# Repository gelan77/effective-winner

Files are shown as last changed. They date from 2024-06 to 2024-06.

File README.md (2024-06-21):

# Проект USB-VGA

Этот репозиторий содержит файлы для проекта USB-VGA, который демонстрирует возможности Raspberry Pi Pico в обработке USB, VGA и аудиовыходов. Ниже приведено краткое описание включенных файлов и их назначения.

## Файлы и директории

- **`CUI_SJ-3523-audio-jack.kicad_mod`**: Модуль KiCad для аудиоразъема.
- **`DSUB-15-L77HDE15SD1CH4F.kicad_mod`**: Модуль KiCad для разъема DSUB-15 VGA.
- **`Icon_`**: Файл иконки для проекта.
- **`MBR120_SOD-123.kicad_mod`**: Модуль KiCad для диода MBR120.
- **`USB-VGA.kicad_mod`**: Модуль KiCad для компонента USB-VGA.
- **`USB-VGA.kicad_pcb`**: Файл макета печатной платы KiCad.
- **`USB-VGA.kicad_prl`**: Файл проекта макета KiCad.
- **`USB-VGA.kicad_pro`**: Файл проекта KiCad.
- **`USB-VGA.kicad_sch`**: Файл схемы KiCad.
- **`USB-VGA.pdf`**: Версия схемы в формате PDF для удобного просмотра.
- **`VGA-USB.xlsx`**: Файл Excel с дополнительными данными о проекте или спецификацией материалов (BOM).
- **`fp-info-cache`**: Файл кеша информации о посадочных местах KiCad.
- **`fp-lib-table`**: Таблица библиотеки посадочных мест KiCad.
- **`sym-lib-table`**: Таблица библиотеки символов KiCad.

## Как использовать

1. **Схемы и макеты печатных плат**: Откройте файлы `.kicad_sch` и `.kicad_pcb` в KiCad для просмотра и редактирования схем и макетов печатных плат.
2. **Компоненты**: Файлы `.kicad_mod` содержат посадочные места для различных компонентов, используемых в проекте.
3. **Документация**: Обратитесь к `USB-VGA.pdf` для быстрого просмотра схемы.
4. **Спецификация материалов**: Файл `VGA-USB.xlsx` может содержать список компонентов и дополнительные детали проекта.

## Начало работы

Чтобы начать работу с этим проектом, клонируйте репозиторий и откройте файлы проекта в KiCad. Убедитесь, что у вас установлены все необходимые библиотеки и модули для беспроблемной работы.

```sh
git clone <repository-url>
```

## Лицензия

Этот проект лицензирован на условиях лицензии MIT. См. файл `LICENSE` для получения подробной информации.

---

Не стесняйтесь исследовать, модифицировать и вносить свой вклад в этот проект. Для любых вопросов или проблем, пожалуйста, откройте issue на странице репозитория.

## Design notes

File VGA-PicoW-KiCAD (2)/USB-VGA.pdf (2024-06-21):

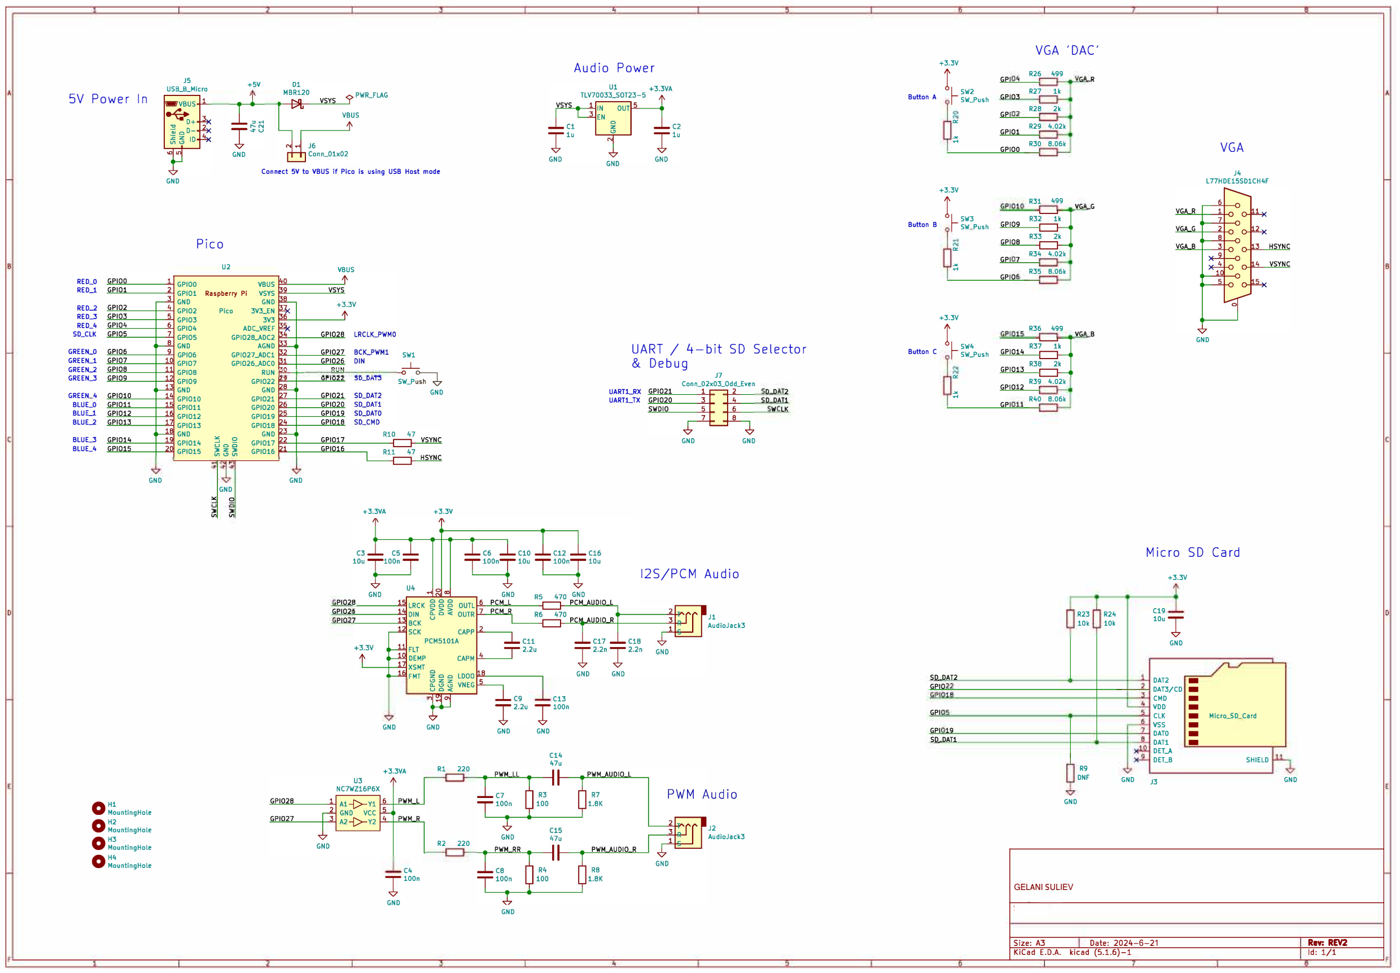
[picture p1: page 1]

5V Power In

RED_O
RED-1
RED-2
RED--3
RE0_4
SD_CLK
GREEN_O
GREEN-1
GREEN--2
GREEN_3
GREEN_4
BLUE_O
BLUU.
BLUE_2
BLUE----3
BLUE_4
GND

O!untingHole
ountingHole
ountingHole
ountingHole

J5
USBJLMicro

GND

Audio Power
+5V

Connect 5V to VBUS if Pico is using USB Host mode GND

Pico
U2
GPIOO VBUS
GPI01 Raspberry Pi VSYS
GND | GND
GPI02 Pico 3V3_EN
GPI03 | 3V3
GPI04 | ADCVREF
GPI05 | GPI028....ADC2
GND | AGND
GPI06 | GPI027_ADC1
GPl07 | GPl026....ADC0
GPIOB | RUN
GPI09 | GPI022
GND | GND
GPI010 | GPI021
GPl011 | GPI020
GPI012 | GPI019
GPI013 | GPI018
GND de | GND
GPI014 | GPI017
GPI015 GPI016
GND
| S'

VBUS

SW1 _l_
r""⁻⁻⁺⁻-~-----oSW_P

GND

PI028
GPI02
PIO 7

GND

+3.3VA +3.3V

GND

+3.3VA

DEMP
XSMT
FMT

C4
1100n
GND

GND

Ri 220

R2 220

GND

GND

C13
1100n
GND
C14
47,

UART/ 4-bit SD Selector
& Debug
UARTLRX
UARTLTX

J7
Conn_02x03_0dd_Even

GND GND

DD 2
SD DAT1

W LK

12S/PCM Audio
Ji
AudioJack3

J2
AudioJack3

+3.3Y
Button A

1
::Po,h

+3.3Y
Button B

1
::',,.,

+3.3Y
Button C

1
::Posh

SD DAT2
GPI0
GPI
GPI 19
SDDAT1

VGA 'DAC'
R26 499
GPI | G R
R27 1k
GPI03
R28 2k
GPI
R29 4.02k
GPI01
R30 8.06k
GPIO0

R31 499
| VG G

R34 4.02k
GPI 7
R35 B.06k
GPIO

R36 499
| VG B

R39 4.02k
GPIO 2
R40 8.06k
GPI

R23
1Dk

R9
DNF
GND

GELANI SULIEV
f
Sheet: /

R24
10k

Micro
+3.3Y
C19
1D,J
GND
DAT2
DAT3/CD
CMD
VDD
CLK

vss
DATO
DAT1
DET....A
DELB
GND J3

VGA
J4
L77HDE15SD1CH4F

GND

SD Card

- Micro_5D Card
SHIELD
GND
Size: A3 | Date: 2024-6-21 | Rev: REV2
KiCad E.D.A. kicad (5.1.6)-1 | Id: 1/1

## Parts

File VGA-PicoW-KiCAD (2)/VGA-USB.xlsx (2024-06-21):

VGA-USB
17/079/2020
Reference designators | Quantity | Manufacturer Part Number (MPN) | Manufacturer | Description | Value
C1, C2 | 2 | GCM188R71C105KA64J | Murata | CAP CER 1UF 16V X7R 0603 | 1u
C9, C11 | 2 | GRM188R71A225KE15D | Murata | CAP CER 2.2UF 10V X7R 0603 | 2.2u
C3, C10, C16, C19 | 4 | GRM188R61A106KE69J | Murata | CAP CER 10UF 10V X5R 0603 | 10u
C4, C5, C6, C7, C8, C12, C13 | 7 | GRM155R71E104KE14J | Murata | CAP CER 0.1UF 25V X7R 0402 | 100n
C14, C15, C21 | 3 | GRM219R60J476ME44D | Murata | CAP CER 47UF 6.3V X5R 0805 | 47u
C17, C18 | 2 | GRM155R71H222KA01D | Murata | CAP CER 2200PF 50V X7R 0402 | 2.2n
D1 | 1 | MBR120VLSFT1G | ON Semiconductor | DIODE SCHOTTKY 20V 1A SOD123FL | MBR120VLSFT1G
J1, J2 | 2 | SJ-3523-SMT-TR | CUI Devices | CONN JACK STEREO 3.5MM SMD R/A | SJ-3523-SMT
J3 | 1 | 104031-0811 | Molex | CONN MICRO SD CARD PUSH-PULL R/A | 104031-0811
J4 | 1 | L77HDE15SD1CH4F | Amphenol ICC (Commercial Products) | CONN DSUB HD RCPT 15POS R/A SLDR | L77HDE15SD1CH4F
J5 | 1 | 10103594-0001LF | Amphenol ICC (FCI) | CONN RCPT USB2.0 MICRO B SMD R/A | 10103594-0001LF
J6 | 1 | TSW-102-23-T-S | Samtec Inc. | CONN HEADER VERT 2POS 2.54MM | TSW-102-23-T-S
J7 | 1 | 67997-208HLF | Amphenol ICC (FCI) | CONN HEADER VERT 8POS 2.54MM | 67997-208HLF
R1, R2 | 2 | RC0402FR-07220RL | Yageo | RES SMD 220 OHM 1% 1/16W 0402 | 220
R3, R4 | 2 | RC0402FR-07100RL | Yageo | RES SMD 100 OHM 1% 1/16W 0402 | 100
R5, R6 | 2 | RC0402FR-07470RP | Yageo | RES SMD 470 OHM 1% 1/16W 0402 | 470
R7, R8 | 2 | RC0402FR-071K8L | Yageo | RES SMD 1.8K OHM 1% 1/16W 0402 | 1.8K
R10, R11 | 2 | RC0402FR-0747RL | Yageo | RES SMD 47 OHM 1% 1/16W 0402 | 47
R20, R21, R22, R27, R32, R37 | 6 | RC0402FR-071KP | Yageo | RES SMD 1K OHM 1% 1/16W 0402 | 1k
R23, R24 | 2 | RC0402FR-0710KP | Yageo | RES SMD 10K OHM 1% 1/16W 0402 | 10k
R26, R31, R36 | 3 | RC0402FR-07499RL | Yageo | RES SMD 499 OHM 1% 1/16W 0402 | 499
R28, R33, R38 | 3 | RC0402FR-072KL | Yageo | RES SMD 2K OHM 1% 1/16W 0402 | 2k
R29, R34, R39 | 3 | RC0402FR-074K02L | Yageo | RES SMD 4.02K OHM 1% 1/16W 0402 | 4.02k
R30, R35, R40 | 3 | RC0402FR-078K06L | Yageo | RES SMD 8.06K OHM 1% 1/16W 0402 | 8.06k
SW1, SW2, SW3, SW4 | 4 | 434133025816 | Würth Elektronik | TACT SWITCH 4.2X3.2MM VERTICAL T | 434133025816
U1 | 1 | TLV70033DDCR | Texas Instruments | IC REG LINEAR 3.3V 200MA SOT23-5 | TLV70033DDCR
U3 | 1 | NC7WZ16P6X | ON Semiconductor | IC BUF NON-INVERT 5.5V SC70-6 | NC7WZ16P6X
U4 | 1 | PCM5101APWR | Texas Instruments | IC DAC 16/24/32BIT 384K 20TSSOP | PCM5101APWR

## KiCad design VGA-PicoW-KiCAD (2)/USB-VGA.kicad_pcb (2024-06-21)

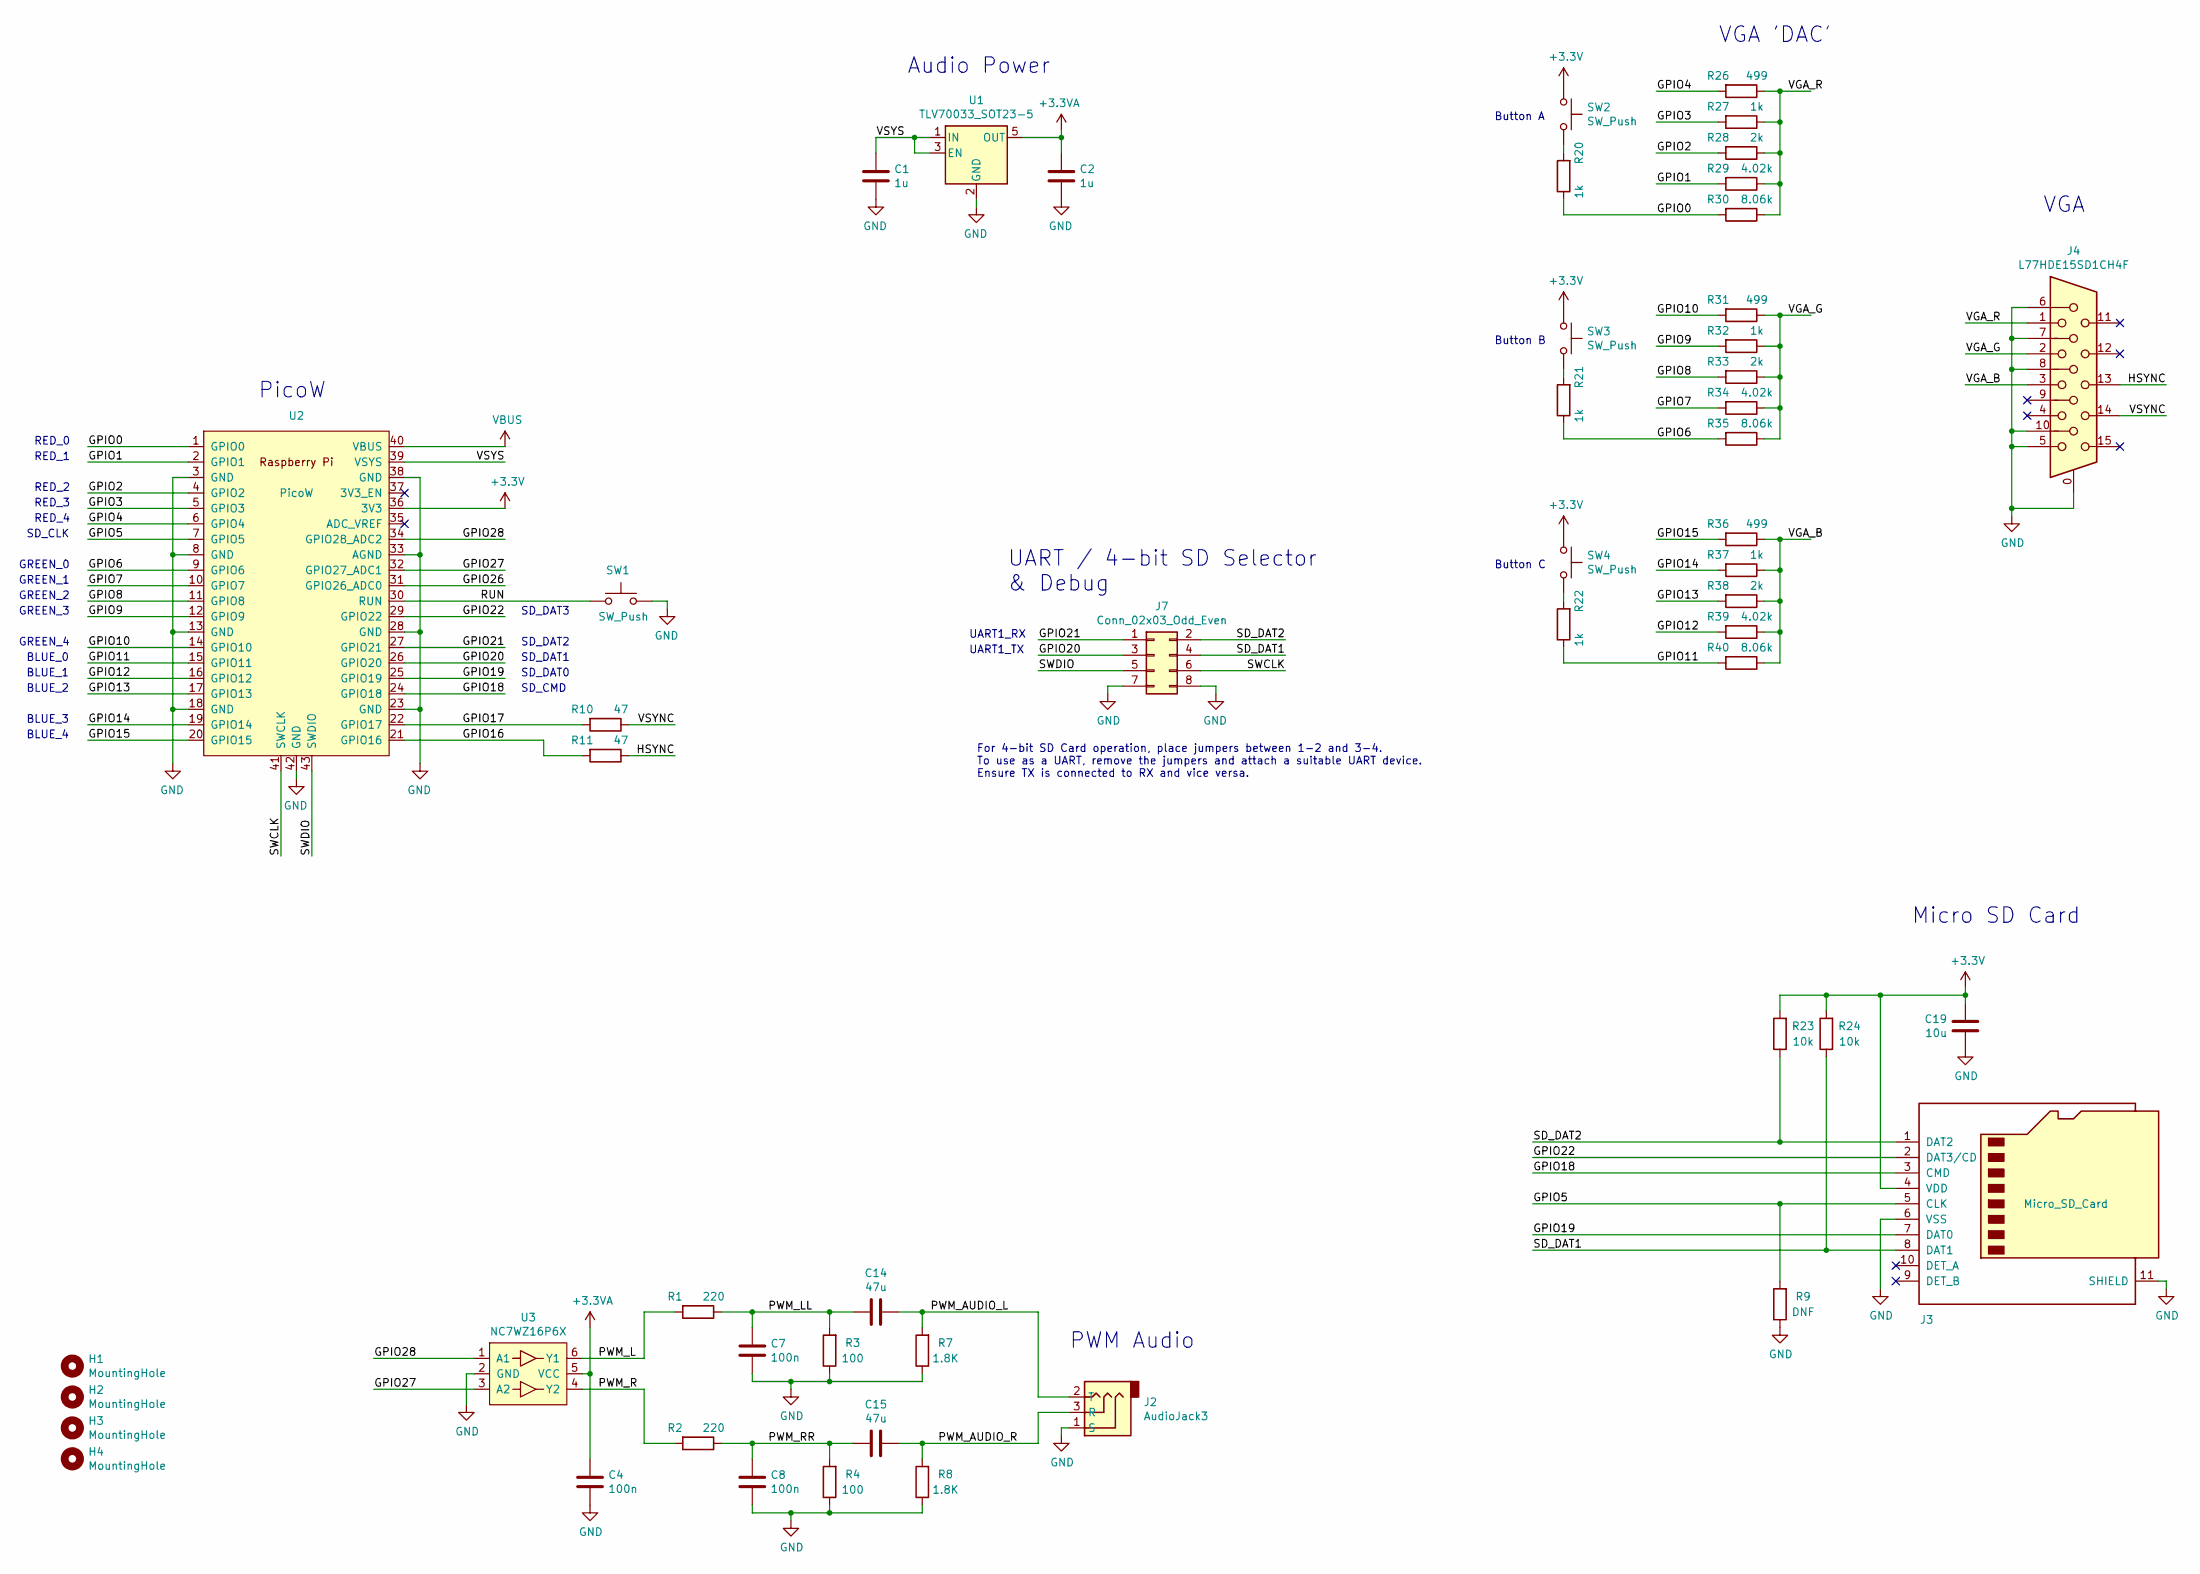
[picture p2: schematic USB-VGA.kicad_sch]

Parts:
C1, C2: 1u; C_0603_1608Metric
C4, C7, C8: 100n; C_0402_1005Metric
C14, C15: 47u; C_0805_2012Metric
C19: 10u; C_0603_1608Metric
H1, H2, H3, H4: MountingHole; MountingHole_2.7mm_M2.5
J2: AudioJack3; CUI_SJ-3523-audio-jack
J3: Micro_SD_Card; microSD_HC_Molex_104031-0811
J4: L77HDE15SD1CH4F; DSUB-15-L77HDE15SD1CH4F
J7: Conn_02x03_Odd_Even; PinHeader_2x04_P2.54mm_Vertical
R1, R2: 220; R_0402_1005Metric
R3, R4: 100; R_0402_1005Metric
R7, R8: 1.8K; R_0402_1005Metric
R9: DNF; R_0402_1005Metric
R10, R11: 47; R_0402_1005Metric
R20, R21, R22, R27, R32, R37: 1k; R_0402_1005Metric
R23, R24: 10k; R_0402_1005Metric
R26, R31, R36: 499; R_0402_1005Metric
R28, R33, R38: 2k; R_0402_1005Metric
R29, R34, R39: 4.02k; R_0402_1005Metric
R30, R35, R40: 8.06k; R_0402_1005Metric
SW1, SW2, SW3, SW4: SW_Push; SW_Push_1P1T_NO_Vertical_Wuerth_434133025816
U1: TLV70033_SOT23-5; SOT-23-5
U2: PicoW; RPi_PicoW_SMD_TH
U3: NC7WZ16P6X; SOT-363_SC-70-6

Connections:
+3.3VA: C2.1, C4.1, U1.5 (OUT), U3.5 (VCC)
+3V3: C19.1, J3.4 (VDD), R23.2, R24.2, SW2.1, SW3.1, SW4.1, U2.36 (3V3)
/GPIO0: R20.1, R30.2, U2.1 (GPIO0)
/GPIO1: R29.2, U2.2 (GPIO1)
/GPIO2: R28.2, U2.4 (GPIO2)
/GPIO3: R27.2, U2.5 (GPIO3)
/GPIO4: R26.2, U2.6 (GPIO4)
/GPIO5: J3.5 (CLK), R9.2, U2.7 (GPIO5)
/GPIO6: R21.1, R35.2, U2.9 (GPIO6)
/GPIO7: R34.2, U2.10 (GPIO7)
/GPIO8: R33.2, U2.11 (GPIO8)
/GPIO9: R32.2, U2.12 (GPIO9)
/GPIO10: R31.2, U2.14 (GPIO10)
/GPIO11: R22.1, R40.2, U2.15 (GPIO11)
/GPIO12: R39.2, U2.16 (GPIO12)
/GPIO13: R38.2, U2.17 (GPIO13)
/GPIO14: R37.2, U2.19 (GPIO14)
/GPIO15: R36.2, U2.20 (GPIO15)
/GPIO16: R11.2, U2.21 (GPIO16)
/GPIO17: R10.2, U2.22 (GPIO17)
/GPIO18: J3.3 (CMD), U2.24 (GPIO18)
/GPIO19: J3.7 (DAT0), U2.25 (GPIO19)
/GPIO20: J7.3, U2.26 (GPIO20)
/GPIO21: J7.1, U2.27 (GPIO21)
/GPIO22: J3.2 (DAT3/CD), U2.29 (GPIO22)
/GPIO26: U2.31 (GPIO26_ADC0)
/GPIO27: U2.32 (GPIO27_ADC1), U3.3 (A2)
/GPIO28: U2.34 (GPIO28_ADC2), U3.1 (A1)
/HSYNC: J4.13, R11.1
/PWM_AUDIO_L: C14.1, J2.2 (T), R7.2
/PWM_AUDIO_R: C15.1, J2.3 (R), R8.2
/PWM_L: R1.2, U3.6 (Y1)
/PWM_LL: C7.1, C14.2, R1.1, R3.2
/PWM_R: R2.2, U3.4 (Y2)
/PWM_RR: C8.1, C15.2, R2.1, R4.2
/RUN: SW1.1, U2.30 (RUN)
/SD_DAT1: J3.8 (DAT1), J7.4, R24.1
/SD_DAT2: J3.1 (DAT2), J7.2, R23.1
/SWCLK: J7.6, U2.41 (SWCLK)
/SWDIO: J7.5, U2.43 (SWDIO)
/VGA_B: J4.3, R36.1, R37.1, R38.1, R39.1, R40.1
/VGA_G: J4.2, R31.1, R32.1, R33.1, R34.1, R35.1
/VGA_R: J4.1, R26.1, R27.1, R28.1, R29.1, R30.1
/VSYNC: J4.14, R10.1
/VSYS: C1.1, U1.1 (IN), U1.3 (EN), U2.39 (VSYS)
GND: C1.2, C2.2, C4.2, C7.2, C8.2, C19.2, J2.1 (S), J3.6 (VSS), J3.11 (SHIELD), J4.0, J4.5, J4.6, J4.7, J4.8, J4.10, J7.7, J7.8, R3.1, R4.1, R7.1, R8.1, R9.1, SW1.2, U1.2 (GND), U2.3 (GND), U2.8 (GND), U2.13 (GND), U2.18 (GND), U2.23 (GND), U2.28 (GND), U2.33 (AGND), U2.38 (GND), U2.42 (GND), U3.2 (GND)
unnamed: R20.2, SW2.2
unnamed: R21.2, SW3.2
unnamed: R22.2, SW4.2
VBUS: U2.40 (VBUS)

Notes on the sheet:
GREEN_0
RED_3
RED_1
SD_DAT2
Button A
VGA
SD_CLK
BLUE_4
BLUE_0
UART1_TX
SD_DAT1
RED_4
PicoW
For 4-bit SD Card operation, place jumpers between 1-2 and 3-4. To use as a UART, remove the jumpers and attach a suitable UART device. Ensure TX is connected to RX and vice versa.
UART1_RX
VGA 'DAC'
Button B
Button C
GREEN_1
UART / 4-bit SD Selector & Debug
SD_DAT0
BLUE_3
SD_CMD
SD_DAT3
Micro SD Card
GREEN_4
RED_2
GREEN_2
Audio Power
PWM Audio
BLUE_1
GREEN_3
BLUE_2
RED_0

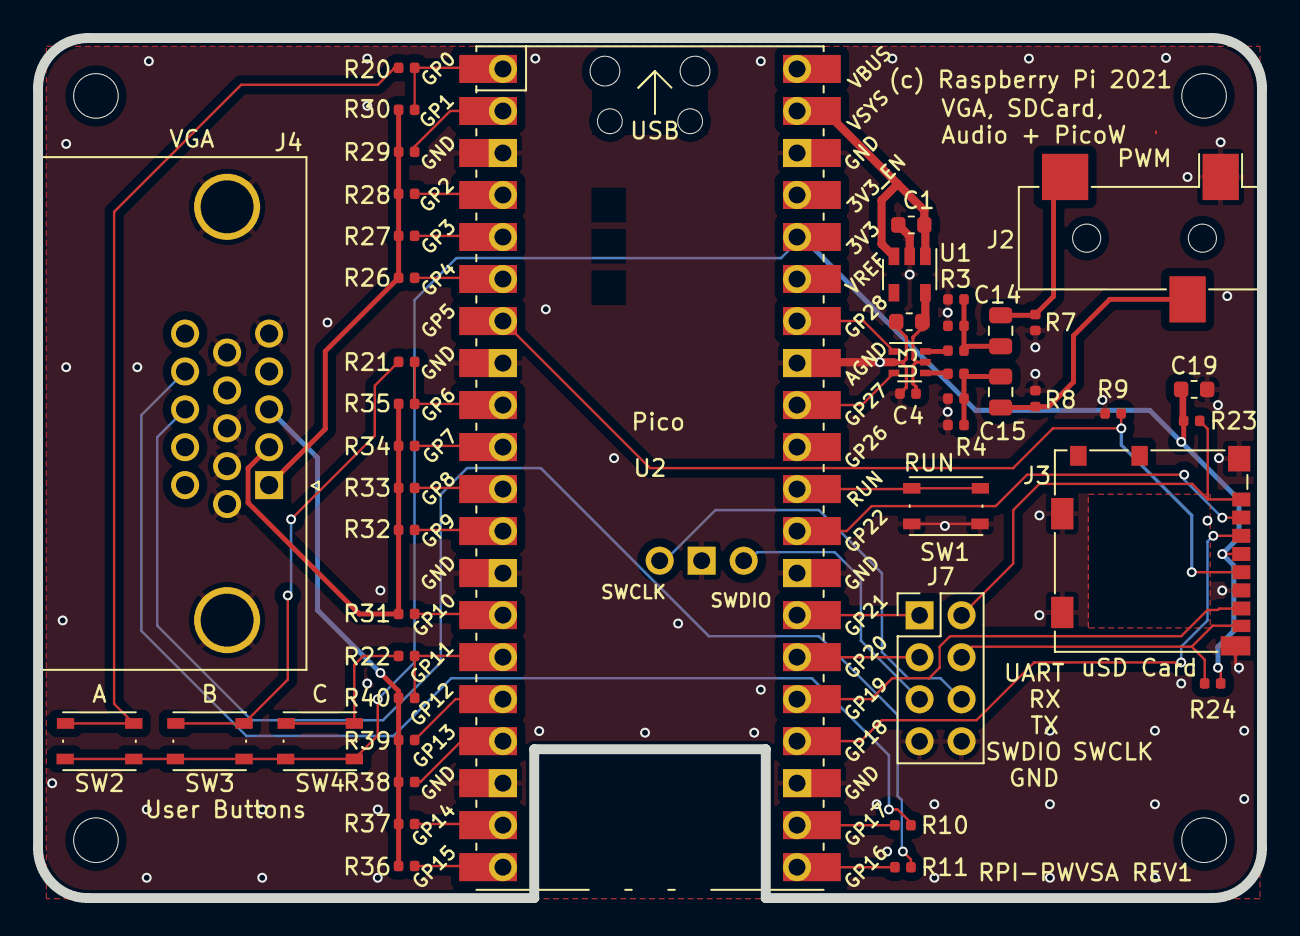
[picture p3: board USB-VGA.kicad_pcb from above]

Board: 4 copper layers, 74.0 x 52.0 mm, 52 parts (0 on the bottom side), 48 nets.
